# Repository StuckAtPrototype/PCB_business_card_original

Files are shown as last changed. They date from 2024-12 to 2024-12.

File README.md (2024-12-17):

# Original business card - StuckAtPrototype

A custom PCB based "business" card that lets you play a version of Flappy Bird.

## Youtube Video
A bit of a back-story of how this project came to be.

My Kickstarter failed, so I open sourced it (https://youtu.be/y-lWarLUhfg)

Sub if you like what you see.

## Project Structure
The project consists of
1. Firmware
2. Hardware

## Firmware
You will need to set up the environment from scratch. You can use any method youd like, but the method mentioned below is probably the easiest.

### Compilation
You will need to obtain chip related code. The "API" from NXP. This comes with Keil uVision. I recommend using it for simplicity. 

The chip is MKE04Z4

# Hardware
I am including everything youd need to make one of these. 

---
## License
### Apache 2.0 -- i.e. use as you'd like
http://www.apache.org/licenses/LICENSE-2.0

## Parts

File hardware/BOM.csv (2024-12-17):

Id | Designator | Footprint | Quantity | Designation | Supplier and ref
1 | C1 | C_0603_1608Metric | 1 | 2.2uF | CL10A225KO8NNNC
2 | R1,R2,R4,R18,R8,R3,R5,R6,R7,R9,R10,R11,R12,R13,R14,R15,R16,R17 | R_0603_1608Metric | 18 | 300 | ESR03EZPF4700 | Note: changed to 470
3 | U1 | QFN-24_4x4_05_test | 1 | MKE04Z8VFK4 | MKE04Z8VFK4
4 | S1 | 6mm_tac_switch | 1 | SWITCH | B3F-1000 | Note: 6mm switch
5 | C2 | C_0603_1608Metric | 1 | 0.1uF | CC0603KRX7R7BB104
6 | J1 | JS202011AQN | 1 | JS202011AQN | JS202011AQN
7 | D1,D2,D3,D7,D8,D9,D10,D11,D12,D13,D14,D15,D16,D17,D18 | LED_0603_1608Metric | 15 | LED | 150060RS75000 | Note: RED
8 | D4,D5,D6 | LED_0603_1608Metric | 3 | LED | 150060GS75000 | Note: Green
9 | R19 | R_0603_1608Metric | 1 | 10k | WR06X103 JTL
10 | BT1 | BAT_2468 | 1 | 2468 | 2468

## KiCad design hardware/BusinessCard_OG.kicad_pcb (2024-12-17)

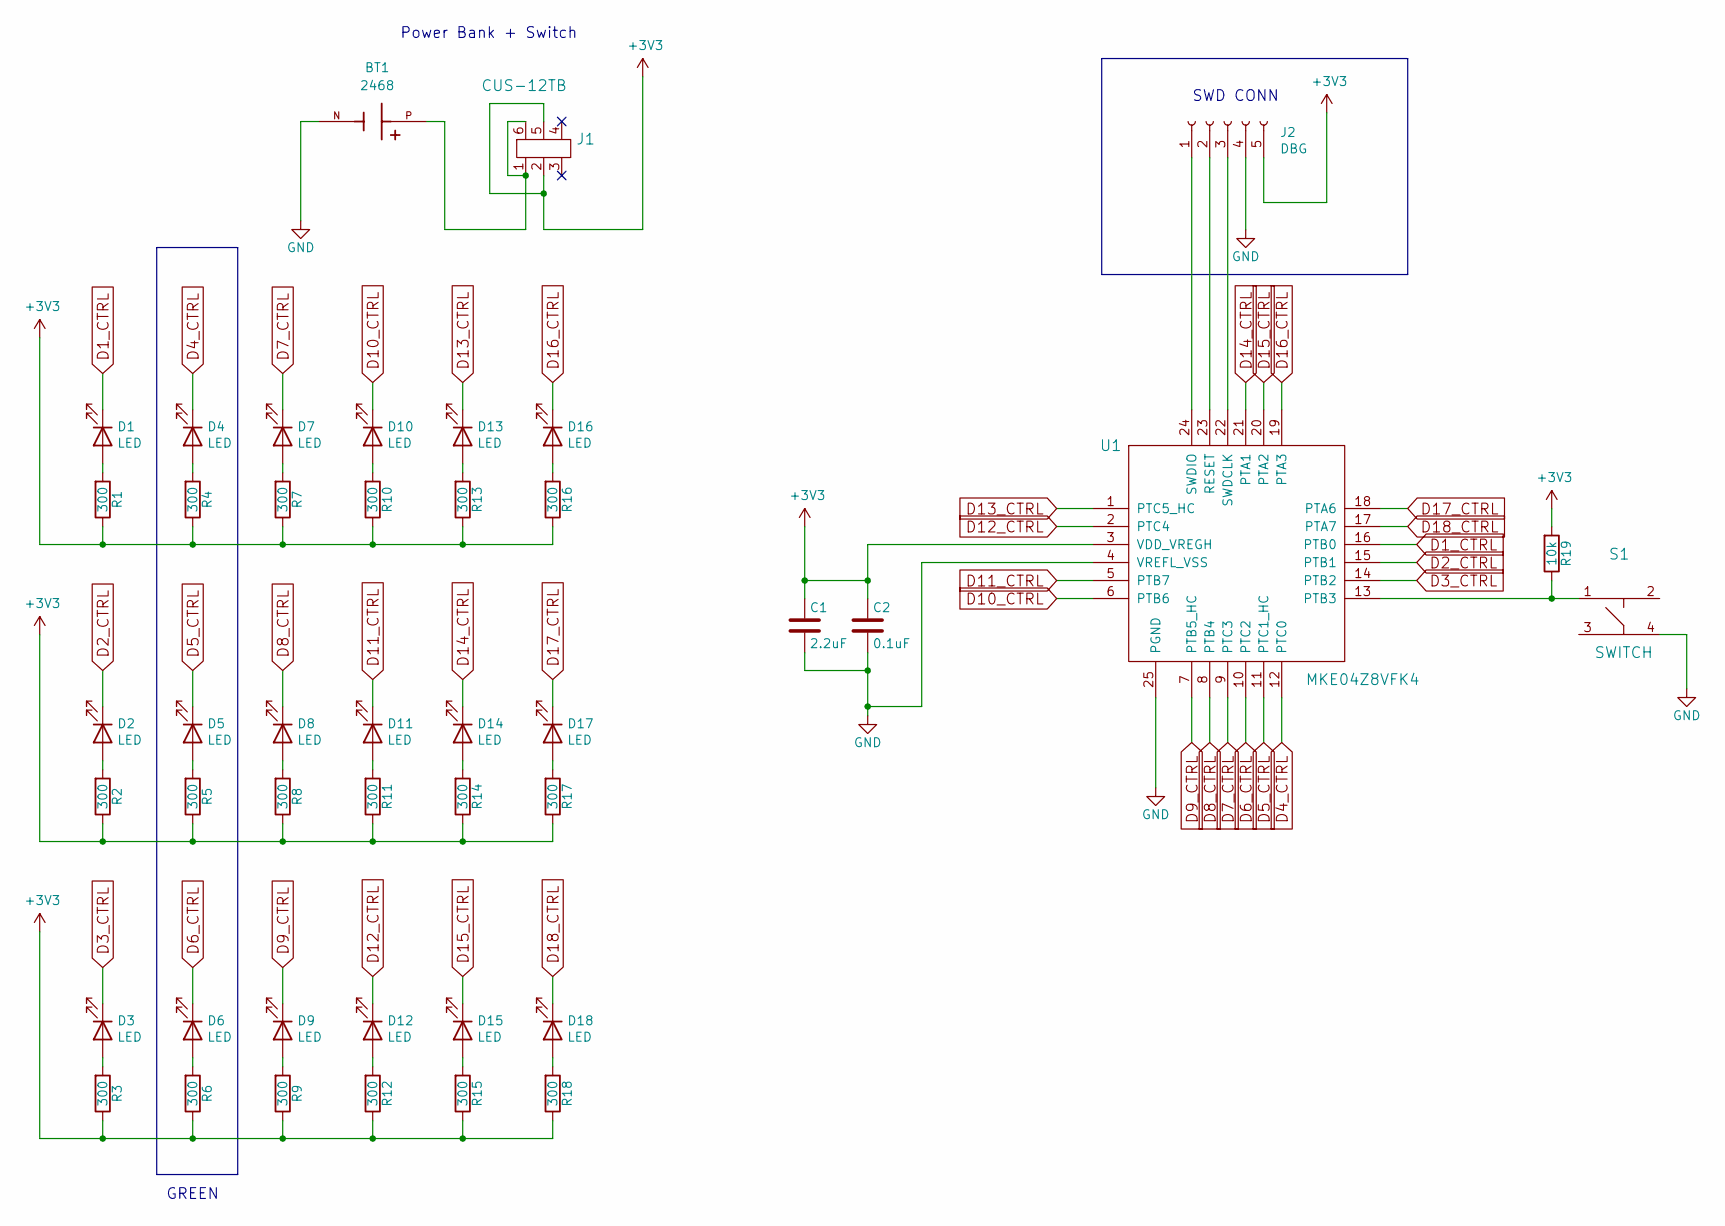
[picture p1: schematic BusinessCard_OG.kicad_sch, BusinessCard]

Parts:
BT1: 2468; BAT_2468; PARTREV D
C1: 2.2uF; C_0603_1608Metric
C2: 0.1uF; C_0603_1608Metric
D1, D2, D3, D4, D5, D6, D7, D8, D9, D10, D11, D12, D13, D14, D15, D16, D17, D18: LED; LED_0603_1608Metric
J1: CUS-12TB; JS202011AQN
J2: DBG; PinHeader_1x05_P1.27mm_Vertical
R1, R2, R3, R4, R5, R6, R7, R8, R9, R10, R11, R12, R13, R14, R15, R16, R17, R18: 300; R_0603_1608Metric
R19: 10k; R_0603_1608Metric
S1: SWITCH; 6mm_tac_switch
U1: MKE04Z8VFK4; QFN-24_4x4_05_test

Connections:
+3V3: C1.1, C2.1, J1.2, J1.5, J2.5, R1.1, R2.1, R3.1, R4.1, R5.1, R6.1, R7.1, R8.1, R9.1, R10.1, R11.1, R12.1, R13.1, R14.1, R15.1, R16.1, R17.1, R18.1, R19.2, U1.3 (VDD_VREGH)
D1_CTRL: D1.1 (K), U1.16 (PTB0)
D2_CTRL: D2.1 (K), U1.15 (PTB1)
D3_CTRL: D3.1 (K), U1.14 (PTB2)
D4_CTRL: D4.1 (K), U1.12 (PTC0)
D5_CTRL: D5.1 (K), U1.11 (PTC1_HC)
D6_CTRL: D6.1 (K), U1.10 (PTC2)
D7_CTRL: D7.1 (K), U1.9 (PTC3)
D8_CTRL: D8.1 (K), U1.8 (PTB4)
D9_CTRL: D9.1 (K), U1.7 (PTB5_HC)
D10_CTRL: D10.1 (K), U1.6 (PTB6)
D11_CTRL: D11.1 (K), U1.5 (PTB7)
D12_CTRL: D12.1 (K), U1.2 (PTC4)
D13_CTRL: D13.1 (K), U1.1 (PTC5_HC)
D14_CTRL: D14.1 (K), U1.21 (PTA1)
D15_CTRL: D15.1 (K), U1.20 (PTA2)
D16_CTRL: D16.1 (K), U1.19 (PTA3)
D17_CTRL: D17.1 (K), U1.18 (PTA6)
D18_CTRL: D18.1 (K), U1.17 (PTA7)
GND: BT1.N, C1.2, C2.2, J2.4, S1.4, U1.4 (VREFL_VSS), U1.25 (PGND)
unnamed: BT1.P, J1.1, J1.6
unnamed: D1.2 (A), R1.2
unnamed: D2.2 (A), R2.2
unnamed: D3.2 (A), R3.2
unnamed: D4.2 (A), R4.2
unnamed: D5.2 (A), R5.2
unnamed: D6.2 (A), R6.2
unnamed: D7.2 (A), R7.2
unnamed: D8.2 (A), R8.2
unnamed: D9.2 (A), R9.2
unnamed: D10.2 (A), R10.2
unnamed: D11.2 (A), R11.2
unnamed: D12.2 (A), R12.2
unnamed: D13.2 (A), R13.2
unnamed: D14.2 (A), R14.2
unnamed: D15.2 (A), R15.2
unnamed: D16.2 (A), R16.2
unnamed: D17.2 (A), R17.2
unnamed: D18.2 (A), R18.2
unnamed: J2.1, U1.24 (SWDIO)
unnamed: J2.2, U1.23 (RESET)
unnamed: J2.3, U1.22 (SWDCLK)
unnamed: R19.1, S1.1, U1.13 (PTB3)

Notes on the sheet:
SWD CONN
GREEN
Power Bank + Switch

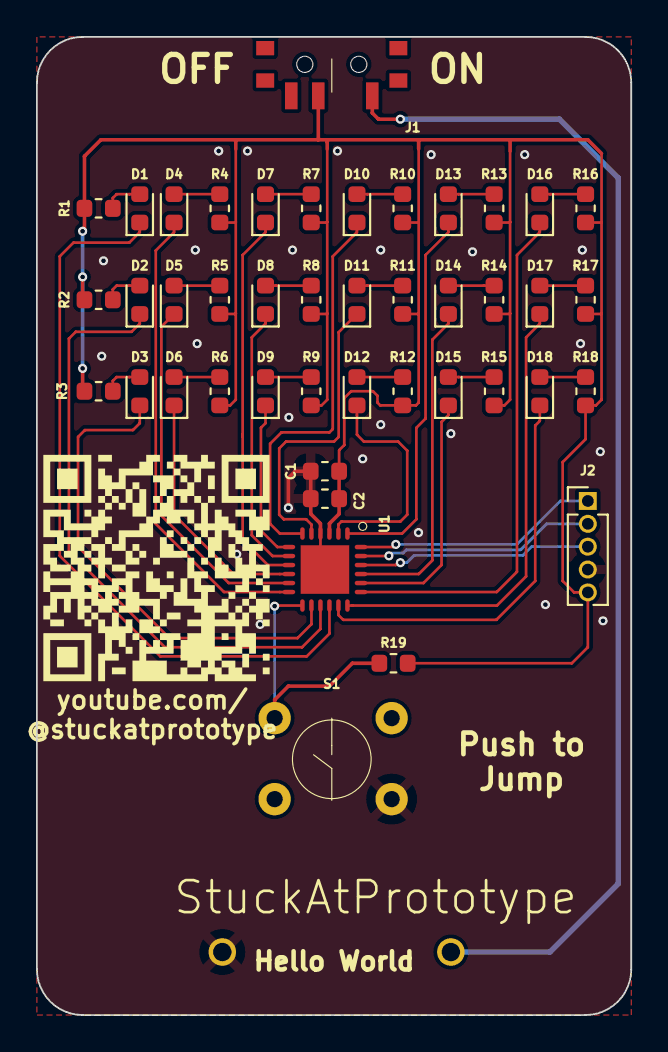
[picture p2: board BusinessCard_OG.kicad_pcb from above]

Board: 4 copper layers, 33.0 x 54.3 mm, 44 parts (1 on the bottom side), 43 nets.

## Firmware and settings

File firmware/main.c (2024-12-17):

#include <stdint.h>
#include <stdlib.h>
#include "MKE04Z4.h" // all chip related crap
#include "typedef.h" // custom bool and etc. 
#include "PIT.h" // PIT driver
#include "LEDS.h" // leds mapping
#include "KBIDriver.h" // KBI driver
#include "GameFunctions.h"
#include "ADC.h" // ADC driver
															
int main (void){
	
		// --- SYSTICK ---
	SysTick_Config(SystemCoreClock /6);
	
	
	// pin 13 is pulled up to batt by 10k resistor
	// this should vary in voltage as battery ages, 
	// as battery is drained and as load varies
	// pin 13 default is ADC0_SE7 - use is as random (init) seed
	// initialize the adc 
	ADCInit();
	
	// read the result from ADC_R	
	// use the result as a random seed for rand() 
	srand(ADCRead());
	
	// disable the adc for power saving
	ADCDisable();
	
	// set up the GPIO 
	for(int i = 0; i < 18; i++){
		// set all leds as output	
		GPIOA->PDDR |= (1u << leds[i]);
		// turn off all leds
		GPIOA->PSOR |= (1u << leds[i]);
		
	}
	
	// disable the NMI 
	SIM->SOPT &= ~(1u << 1);
	
	// initialize the KBI module
	KBIInit();
		
	// initialize PIT 
	PIT_Init();
	

	// rest of the program is executed based on interrupts
	// either from button press or timers
	// never quit 	
	while(1)
		__nop();
	
}

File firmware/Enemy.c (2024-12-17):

#include "Enemy.h"

// enemy screen in pixels. 0 = off, 1 = on
uint16_t current_enemy_screen[3][7] = {
																				{0, 0, 0, 0, 0, 0, 0},
																				{0, 0, 0, 0, 0, 0, 0},
																				{0, 0, 0, 0, 0, 0, 0}
																			};
	
// enemy figures 
uint16_t enemy_3d[7][3][2] = {

	{
		{0,0},
		{0,0},
		{1,0}
	},
	{
		{0,0},
		{1,0},
		{1,0}
	},
	{
		{0,0},
		{1,0},
		{1,0}
	},
		{
		{0,0},
		{1,1},
		{0,0}
	},
	{
		{0,0},
		{1,0},
		{0,0}
	},
	{
		{1,0},
		{1,0},
		{0,0}
	},
		{
		{0,0},
		{0,0},
		{1,0}
	}
};

// delay for the next enemy generation
uint16_t delay = 3; 
uint16_t delay_tick = 0;

// speed of the game 
const uint32_t game_speed_const = 4500000; // 4500000
uint32_t game_speed = 4500000; 
const uint32_t game_speed_min = 2750000; // 2750000 = 114ms || 3500000 = 146ms
const uint32_t game_speed_step = 5000;

// light up a specific LED
void EnemyControlLEDDirect(uint16_t row, uint16_t col, uint16_t value){
	
	// if 1 turn on, if 0 turn off
	if(value == 1)
		GPIOA->PCOR = (1u << enemy_screen_definition[row][col]);
	else
		GPIOA->PSOR = (1u << enemy_screen_definition[row][col]);
}

// clear the enemy screen
// does not turn off leds unless EnemyAnimate is ran! 
void EnemyClearScreen(void){
		// clear current enemy screen
	for(int i = 0; i < 3; i++){
		for(int b = 0;b < 7; b++){
			current_enemy_screen[i][b] = 0;
		}
	}
}

// initialize or re-initialize 
void EnemyInit(uint32_t seed){
	
	// pass in the seed
	srand(seed);
	
	// clear enemy screen
	EnemyClearScreen();
	
	// game_speed reset
	game_speed = game_speed_const;
	
	// reset the delay tick
	delay_tick = 0;
}


void EnemyScreenRedraw(void){
		// turn on/off leds 
	for(int i = 0; i < 3; i++){
		for(int b = 0; b < 5; b++){
			// turn off the led if 0 turn on if 1
			if(current_enemy_screen[i][b] == 0)
				GPIOA->PSOR = (1u << enemy_screen_definition[i][b]);
			else 
				GPIOA->PCOR = (1u << enemy_screen_definition[i][b]);
		}
	}
}


// animates and renders the pixels
void EnemyAnimate(){

	// translate the enemy screen left by 1 column
	for(int i = 0; i < 6; i++){
		// translate entire colum
		for(int b = 0; b < 3; b++)
			current_enemy_screen[b][i] = current_enemy_screen[b][i+1];
	}		
	// clear the last 3 
	for(int i = 0; i < 3; i++)
		current_enemy_screen[i][6] = 0;
	
	// redraw the screen
	EnemyScreenRedraw();
	
}	


void GenerateEnemy(){
	
	// generate a random number
	int num = rand(); // 0 to 0x7FFFFFFF
	num /= 306783378; 
	
	// just in case
	if(num >= 7)
		num = 6;
	
	// set up an enemy
	for(int i = 0; i < 3; i++){
		for(int b = 0; b < 2; b++){
			current_enemy_screen[i][b + 5] = enemy_3d[num][i][b];
		}
	}
	
}

// adjust the enemy speed as game progresses
void EnemySpeedAdjust(void){
	
	// adjust the game speed at different rates through out
	if(game_speed > (game_speed_min + 300000)){
		game_speed -= game_speed_step;
	}
	else if(game_speed > game_speed_min){
		game_speed -= game_speed_step/5;
	}
	
}

// PIT 1 (PWM) interrupt
// main loop for enemy
// takes care of animating enemy
// and checking if jumper has been hit
void PIT_CH1_IRQHandler(void){
	
	// animate the screen
	EnemyAnimate();

	
/* uncomment if you want the jumper to be automated
	if(current_enemy_screen[2][3] == 1)
		// run the jumper! 
		JumperSetEnergy(4);
	else if(current_enemy_screen[2][2] == 1)
		// run the jumper! 
		JumperSetEnergy(4);
*/
	
	
	// check if jumper hit an enemy
	for(int i = 0; i < 3; i++){
		
		// check if the enemy screen is a 1
		if(current_enemy_screen[i][0] == 1){
			if(jumper_pos == 2 - i){
				// jumper hit! 	
				// end the game
				GameStop();
				
				// reset the frequency of the PIT timer -- might not need this
				PIT->CHANNEL[1].LDVAL = game_speed_const;
				
				PIT->CHANNEL[1].TFLG = 0x1; // clear the irq
				NVIC_ClearPendingIRQ(PIT_CH1_IRQn); // clear ARM irq
				
				return;
			}
		
		}
			
	}
	
	// generate a new enemy if delay allows
	if( delay_tick >= delay){
		GenerateEnemy();
		delay_tick = 0;
		
		// establish the next delay 3 to 8
		int num = rand(); // 0 to 0x7fffff
		num /= 429496729; 
		num += 3;
		
		if(num >= 9)
			num = 8;
		
		delay = num;
	}
	else
		delay_tick++;

	// make the game faster
	EnemySpeedAdjust();

	
		// reset the frequency of the PIT timer with new game speed
	PIT->CHANNEL[1].LDVAL = game_speed;
	
	PIT->CHANNEL[1].TFLG = 0x1; // clear the irq
	NVIC_ClearPendingIRQ(PIT_CH1_IRQn); // clear ARM irq
	
}
